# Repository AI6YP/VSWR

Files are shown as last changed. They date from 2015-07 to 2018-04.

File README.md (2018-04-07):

# VSWR
VSWR / Return loss analyzer

## Schematic

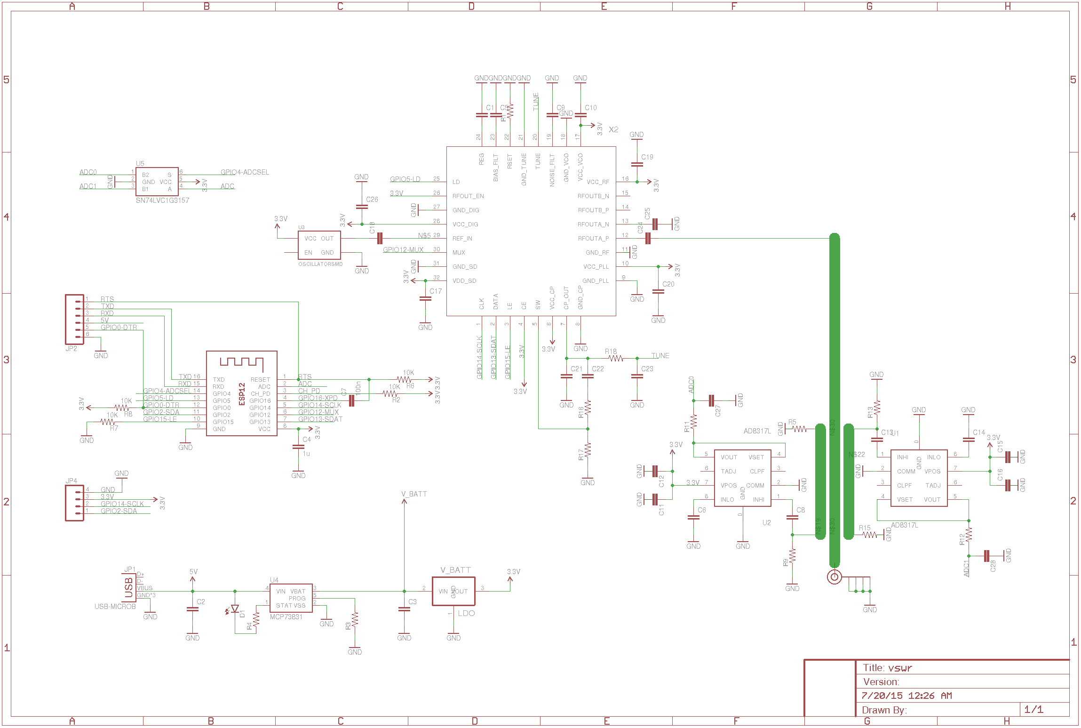
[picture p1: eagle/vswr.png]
schematic


## PCB

### Top

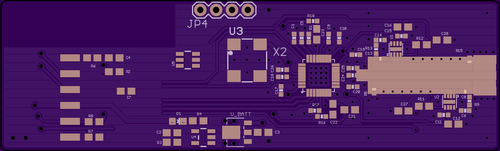
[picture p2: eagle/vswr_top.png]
PCB Top


### Bottom

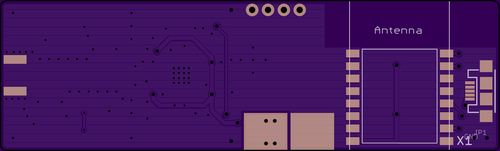
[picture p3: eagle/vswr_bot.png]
PCB Bottom


## Parts

| pos | type | size | value |
|-----|---|---|---|
| C6, C8, C13, C14 | NP0 | 0603 | 100pF |
| C11, C15 | X7R | 0603 | 0.1uF |
| C12, C16 | NP0 | 0603 | 100nF |
| R9, R13 | RC | 0603 | 100 |
| R9a, R13a | RC | 0603 | 110 |
| R11, R12 | RC | 0603 | 1K |

### Directional coupler
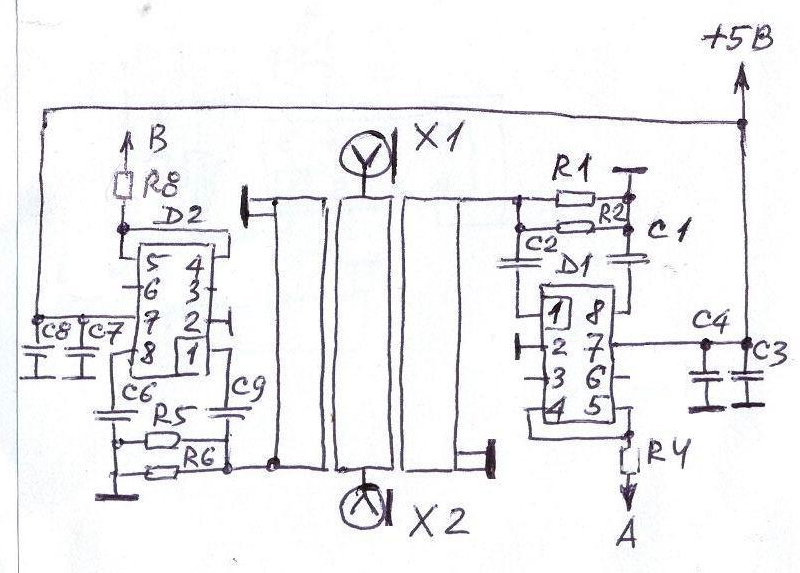
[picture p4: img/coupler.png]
coupler


### RMS Power Detector
LTC5587

Name                                             | $     | Frequency     | Input Range    | Package  | Interface
------------------------------------------------ | ----- | ------------- | -------------- | -------- | ---------
[LMH2110TM](http://www.digikey.com/short/tc024d) | 2.30  | 50MHz ~ 8GHz  | -40dBm ~ 5dBm  | 6-WFBGA  | analog
[LTC5531](http://www.digikey.com/short/tc02f4)   | 3.07  | 300MHz ~ 7GHz | -32dBm ~ 10dBm | SOT-23-6 | analog
[AD8317](http://www.digikey.com/short/t7rp3d)    | 9.75  | 1MHz ~ 10GHz  | -53dBm ~ -3dBm | 8-VFDFN  | analog
[AD8319](http://www.digikey.com/short/tc02hf)    | 4.84  | 1MHz ~ 10GHz  | -43dBm ~ -3dBm | 8-VFDFN  | analog
[LTC5587](http://www.digikey.com/short/tc02dt)   | 11.03 | 10MHz ~ 6GHz  | -34dBm ~ 6dBm  | 12-WFDFN | SPI

### RF Synthesizer/VCO

Name                                           | $     | Frequency        | Package | Interface
---------------------------------------------- | ----- | ---------------- | ------- | ---------
[MAX2871](http://www.digikey.com/short/t7rz2d) | 11.12 | 23.5 .. 6000 MHz | TQFN-32 | SPI
[LMX2592](http://www.digikey.com/short/3j1prr) | 36.72 | 20 .. 9800 MHz   | WQFN-40 | SPI
[LMX2582](http://www.digikey.com/short/3j1p25) | 20.49 | 20 .. 5500 MHz   | WQFN-40 | SPI

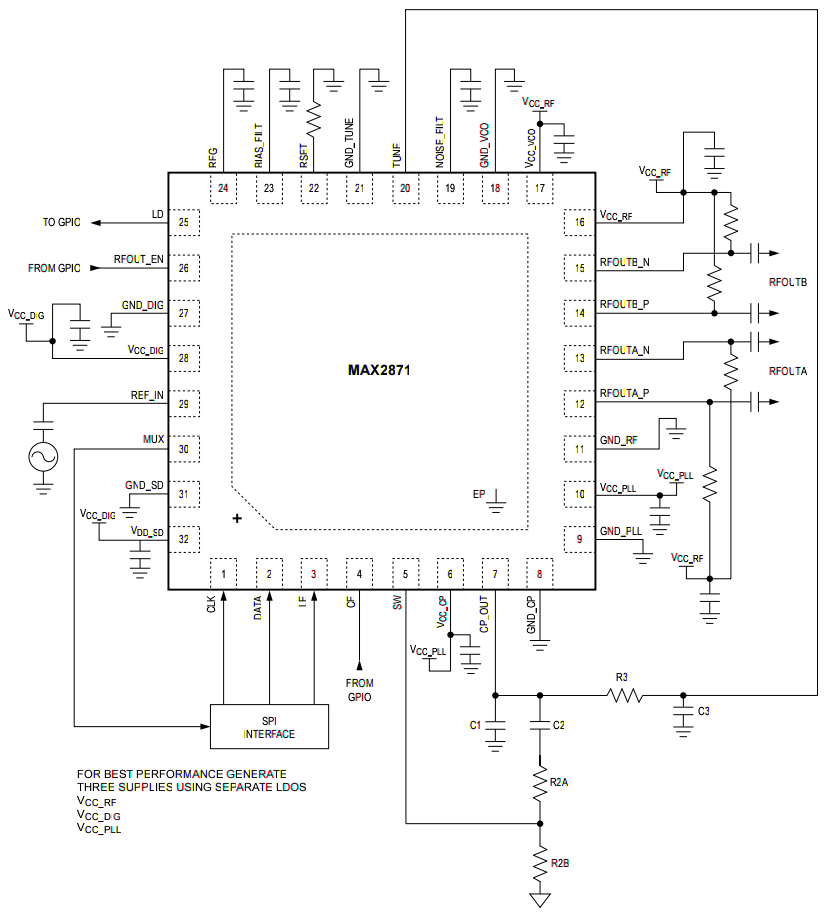
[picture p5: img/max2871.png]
max2871


### WiFi interface
[ESP8266 SMD board](http://www.electrodragon.com/w/ESP8266_SMD_Board) board $4

[ESP-12E](http://www.electrodragon.com/product/esp-12e-esp8266-wifi-board/) / [ESP-13](http://www.electrodragon.com/product/esp-13-esp8266-wifi-board/)

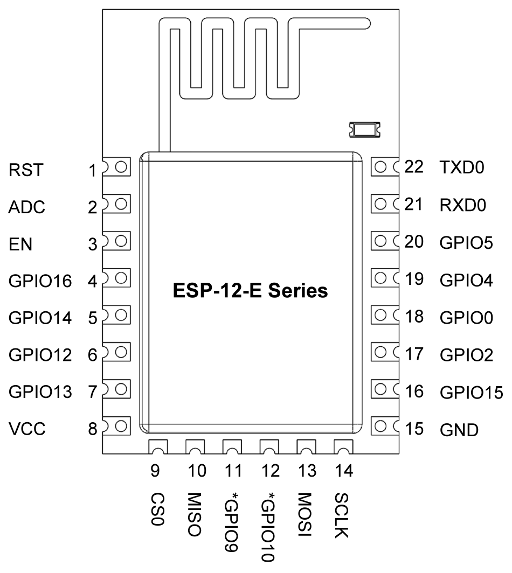
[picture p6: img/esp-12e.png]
ESP-13


### Power

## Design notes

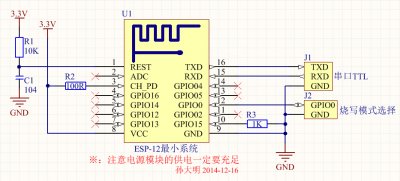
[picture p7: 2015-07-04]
img/esp-13.jpg

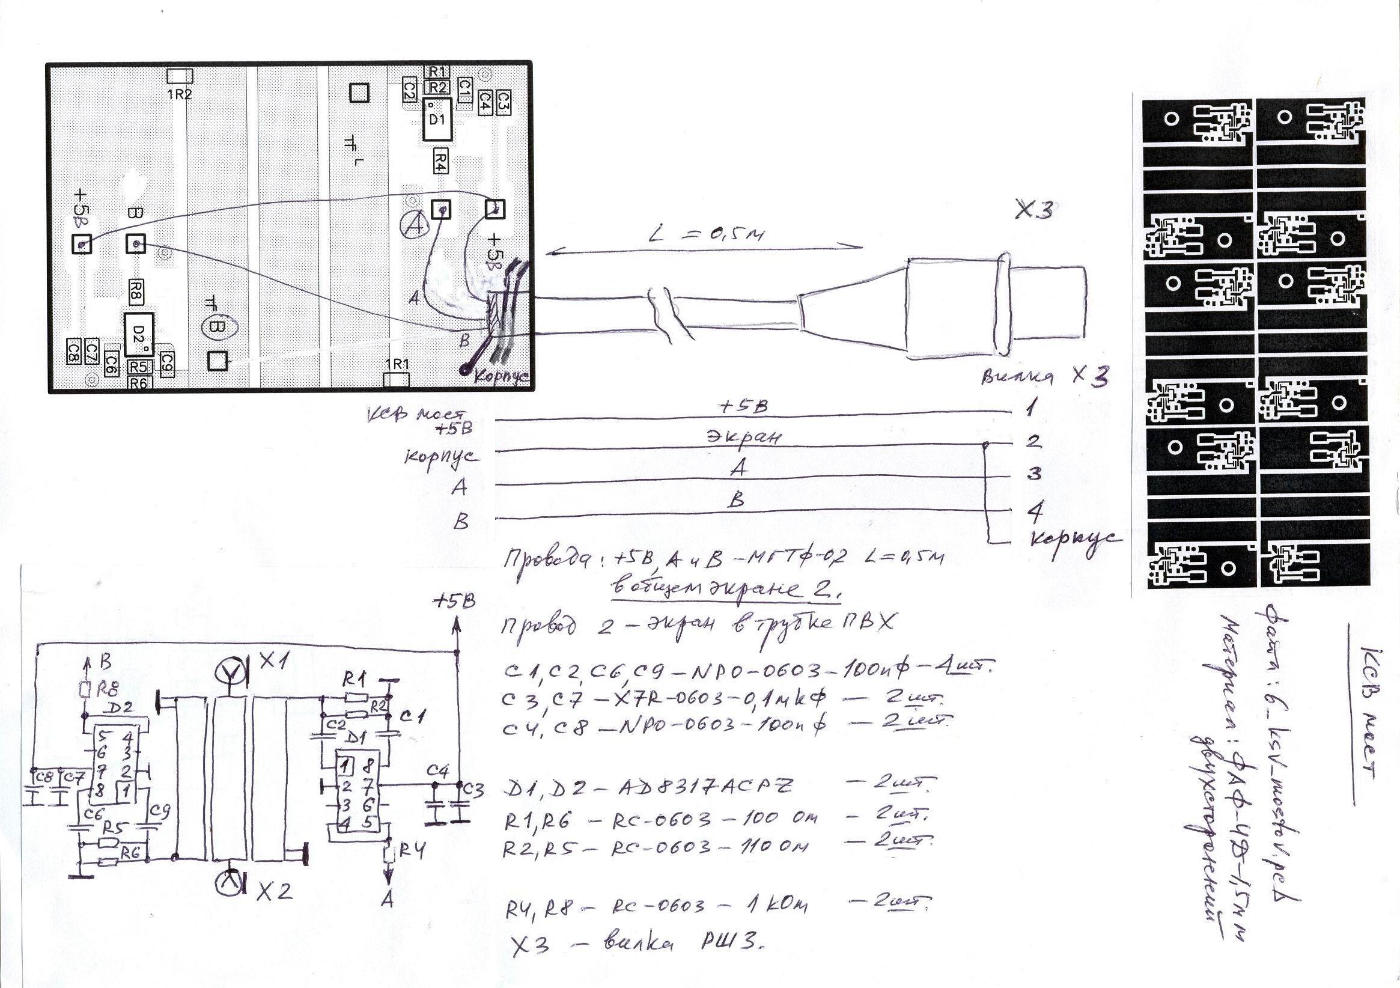
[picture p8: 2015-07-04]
img/Directional coupler_sch.jpg

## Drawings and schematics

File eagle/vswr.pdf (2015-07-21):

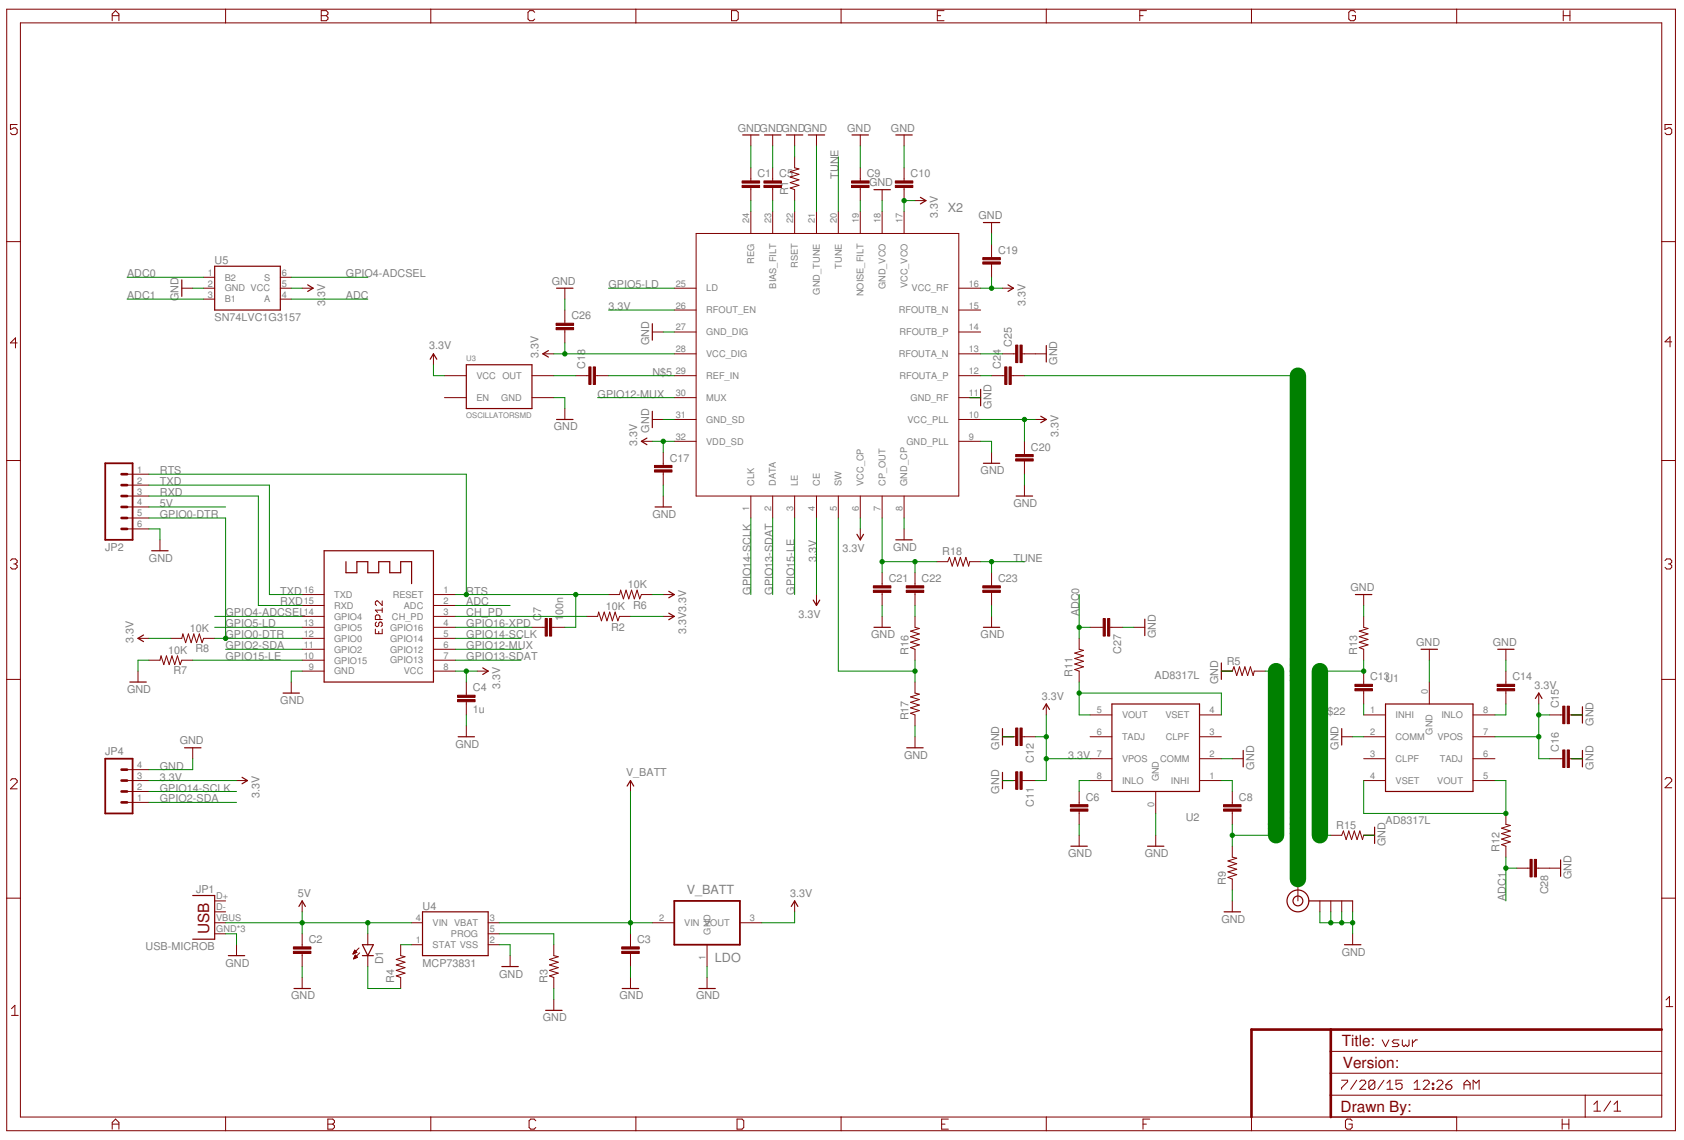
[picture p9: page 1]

Drawn By: Title: Version:

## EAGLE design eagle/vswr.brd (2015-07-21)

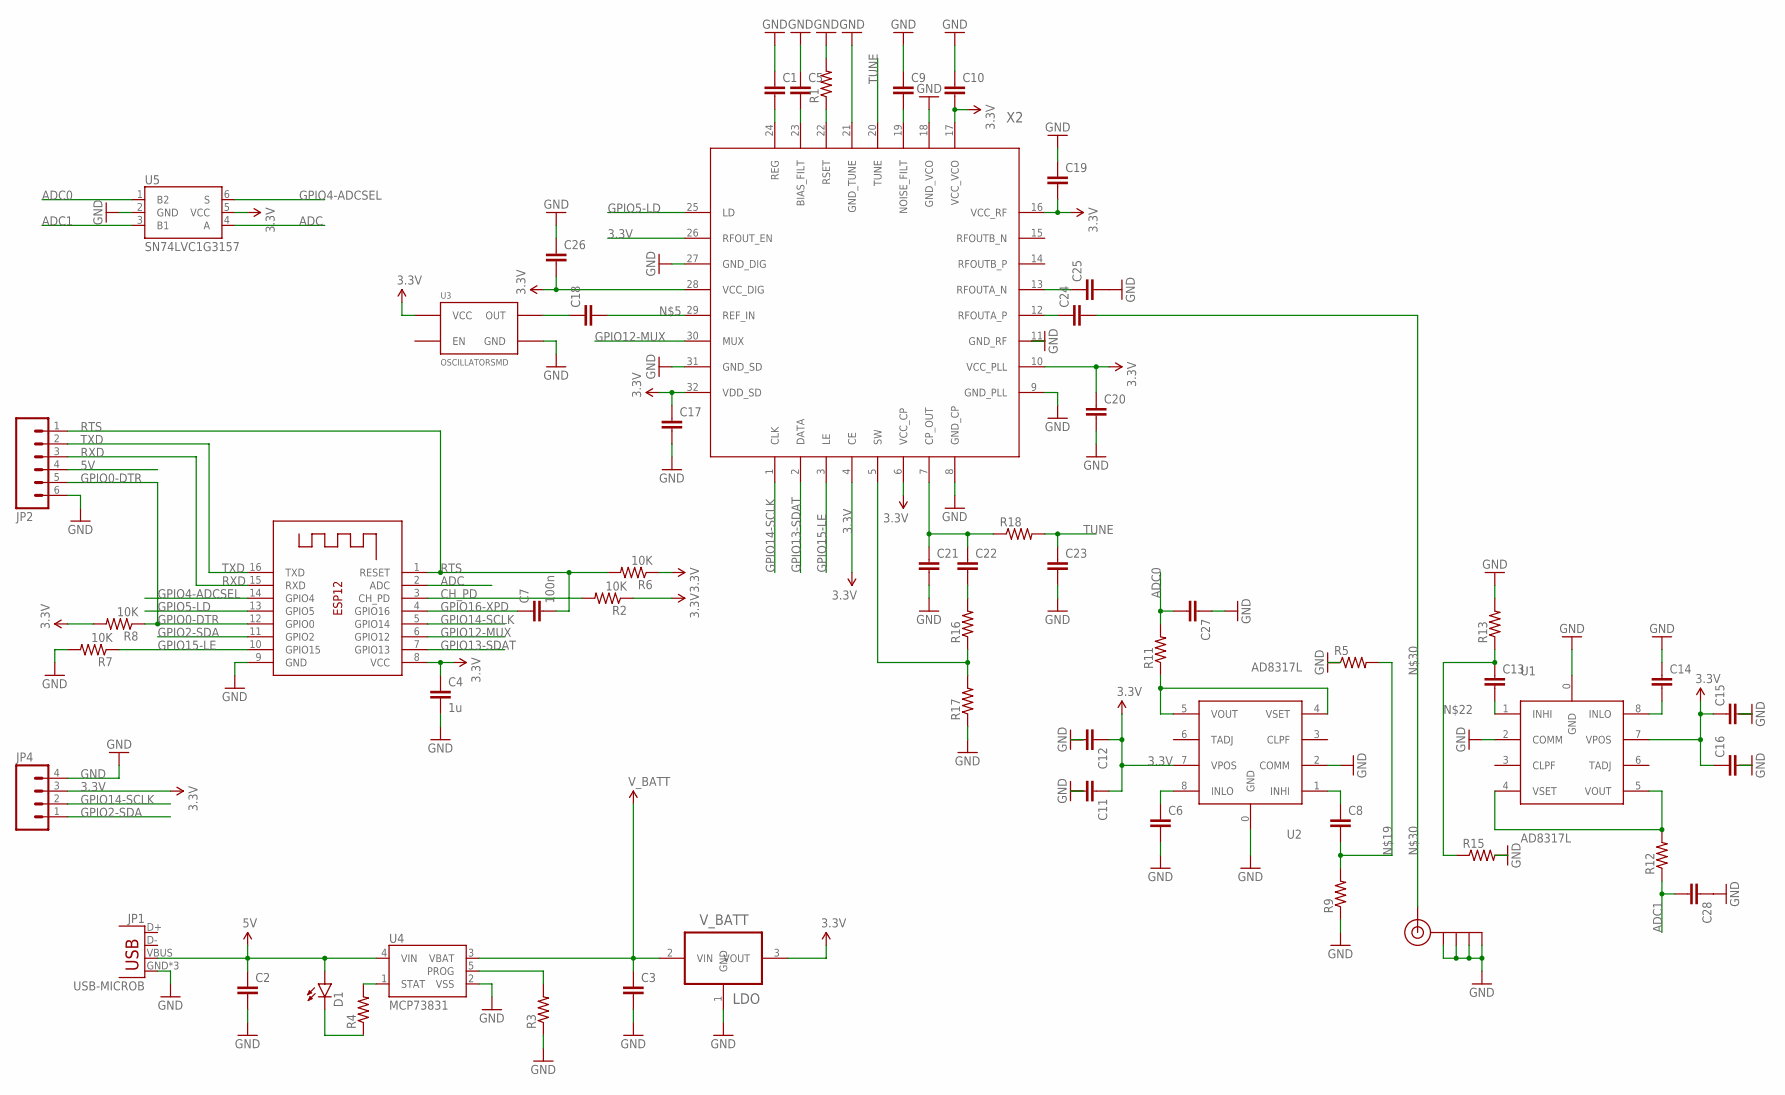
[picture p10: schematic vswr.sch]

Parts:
C1, C5, C6, C8, C9, C10, C11, C13, C14, C15, C17, C18, C19, C20, C24, C25, C26: CAP0402; 0402
C2, C3, C12, C16, C21, C22, C23, C27, C28: CAP0603; 0603
C4: 1u; 0603
C7: 100n; 0603
D1: LED0603; LED-0603
J$1: SMA_EDGE; SMA-EDGE
JP1: USB-MICROB
JP2: M061X06-SMD_EDGE_FEMALE; 1X06-SMD_EDGE
JP4: M04PTH; 1X04
R1, R5, R9, R13, R15, R16, R17, R18: RESISTOR0402; 0402
R2, R6, R7, R8: 10K; 0603
R3, R4, R11, R12: RESISTOR0603; 0603
U1, U2: AD8317L; DFN-8-EXTRA
U3: OSCILLATORSMD; CRYSTAL-SMD-7X5
U4: MCP73831; SOT23-5
U5: SN74LVC1G3157; SOT23-6
V_BATT: LDO; SOT89R
X1: ESP-12
X2: MAX2870TQFN-32-EXTRA; TQFN-32-EXTRA

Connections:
3.3V: C4.1, C10.2, C11.1, C12.1, C15.1, C16.1, C17.1, C19.2, C20.1, C26.2, JP4.3, R2.1, R6.1, R8.2, U1.7 (VPOS), U2.7 (VPOS), U3.P$4 (VCC), U5.5 (VCC), V_BATT.3 (VOUT), X1.8 (VCC), X2.4 (CE), X2.6 (VCC_CP), X2.10 (VCC_PLL), X2.16 (VCC_RF), X2.17 (VCC_VCO), X2.26 (RFOUT_EN), X2.28 (VCC_DIG), X2.32 (VDD_SD)
5V: C2.1, D1.A, JP1.VBUS, JP2.4, U4.4 (VIN)
ADC: U5.4 (A), X1.2 (ADC)
ADC0: C27.2, R11.2, U5.1 (B2)
ADC1: C28.2, R12.1, U5.3 (B1)
CH_PD: R2.2, X1.3 (CH_PD)
GND: C1.1, C2.2, C3.2, C4.2, C5.1, C6.2, C9.1, C10.1, C11.2, C12.2, C14.1, C15.2, C16.2, C17.2, C19.1, C20.2, C21.2, C23.2, C25.2, C26.1, C27.1, C28.1, J$1.GND@0 (GND), J$1.GND@1 (GND), J$1.GND@2 (GND), J$1.GND@3 (GND), JP1.GND, JP1.MT1 (GND), JP1.MT2 (GND), JP2.6, JP4.4, R1.2, R3.1, R5.1, R7.2, R9.1, R13.2, R15.2, R17.1, U1.0 (GND), U1.2 (COMM), U2.0 (GND), U2.2 (COMM), U3.P$2 (GND), U4.2 (VSS), U5.2 (GND), V_BATT.1 (GND), X1.9 (GND), X2.8 (GND_CP), X2.9 (GND_PLL), X2.11 (GND_RF), X2.18 (GND_VCO), X2.21 (GND_TUNE), X2.27 (GND_DIG), X2.31 (GND_SD)
GPIO0-DTR: JP2.5, R8.1, X1.12 (GPIO0)
GPIO2-SDA: JP4.1, X1.11 (GPIO2)
GPIO4-ADCSEL: U5.6 (S), X1.14 (GPIO4)
GPIO5-LD: X1.13 (GPIO5), X2.25 (LD)
GPIO12-MUX: X1.6 (GPIO12), X2.30 (MUX)
GPIO13-SDAT: X1.7 (GPIO13), X2.2 (DATA)
GPIO14-SCLK: JP4.2, X1.5 (GPIO14), X2.1 (CLK)
GPIO15-LE: R7.1, X1.10 (GPIO15), X2.3 (LE)
GPIO16-XPD: C7.1, X1.4 (GPIO16)
unnamed: C1.2, X2.24 (REG)
unnamed: C5.2, X2.23 (BIAS_FILT)
unnamed: C9.2, X2.19 (NOISE_FILT)
unnamed: C18.2, X2.29 (REF_IN)
unnamed: D1.C, R4.1
unnamed: C13.2, U1.1 (INHI)
unnamed: R1.1, X2.22 (RSET)
unnamed: C6.1, U2.8 (INLO)
unnamed: C25.1, X2.13 (RFOUTA_N)
unnamed: C8.1, U2.1 (INHI)
unnamed: C8.2, R5.2, R9.2
unnamed: R11.1, U2.4 (VSET), U2.5 (VOUT)
unnamed: C18.1, U3.P$3 (OUT)
unnamed: C13.1, R13.1, R15.1
unnamed: C21.1, C22.1, R18.1, X2.7 (CP_OUT)
unnamed: C24.1, X2.12 (RFOUTA_P)
unnamed: C14.2, U1.8 (INLO)
unnamed: C22.2, R16.2
unnamed: R12.2, U1.4 (VSET), U1.5 (VOUT)
unnamed: R16.1, R17.2, X2.5 (SW)
unnamed: C24.2, J$1.SIG (SIGNAL)
PROG: R3.2, U4.5 (PROG)
RTS: C7.2, JP2.1, R6.2, X1.1 (RESET)
RXD: JP2.3, X1.15 (RXD)
STAT: R4.2, U4.1 (STAT)
TUNE: C23.1, R18.2, X2.20 (TUNE)
TXD: JP2.2, X1.16 (TXD)
V_BATT: C3.1, U4.3 (VBAT), V_BATT.2 (VIN)

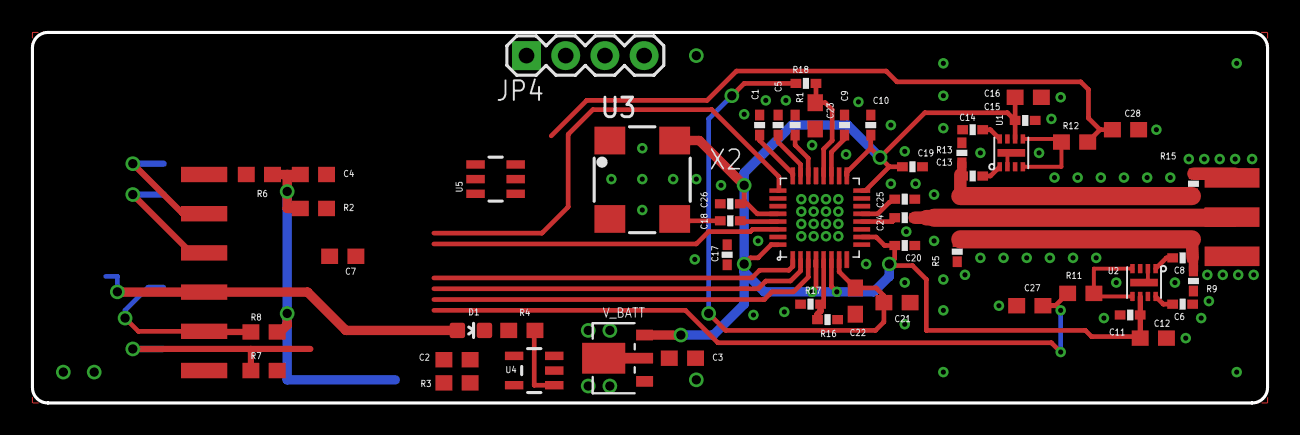
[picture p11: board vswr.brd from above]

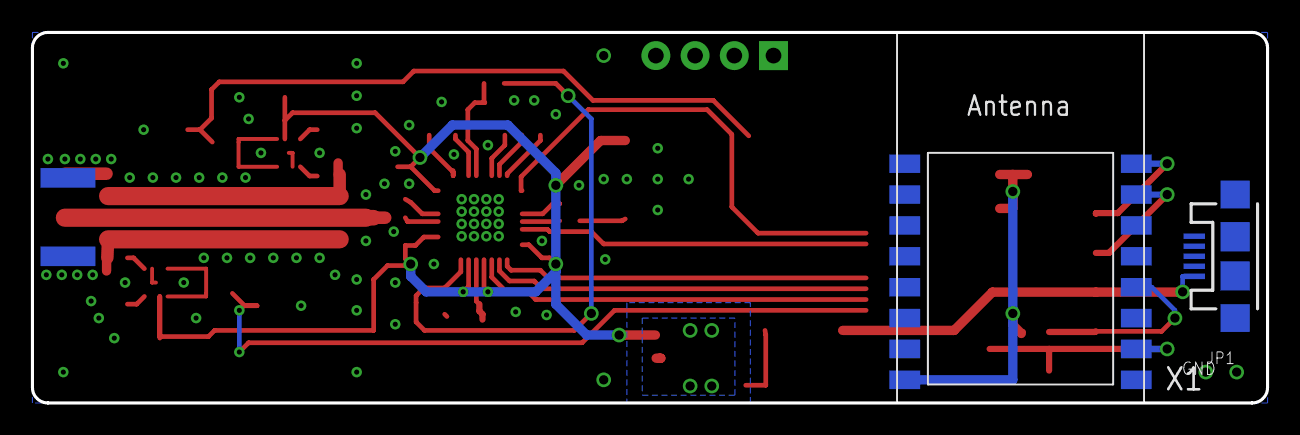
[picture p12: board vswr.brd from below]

Board: 2 copper layers, 80.0 x 24.0 mm, 57 parts (2 on the bottom side), 44 nets.

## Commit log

2015-07-04 added schematics
2015-07-21 added initial schematic and pcb files
    [vswr.brd, vswr.sch]
2015-07-21 added pcb images

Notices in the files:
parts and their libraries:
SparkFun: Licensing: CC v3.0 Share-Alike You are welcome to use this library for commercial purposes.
